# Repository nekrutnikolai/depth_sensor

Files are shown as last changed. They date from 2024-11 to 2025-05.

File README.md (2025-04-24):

## Low-Cost Depth Sensing Module For Deep-Water Instruments

<p align="center">
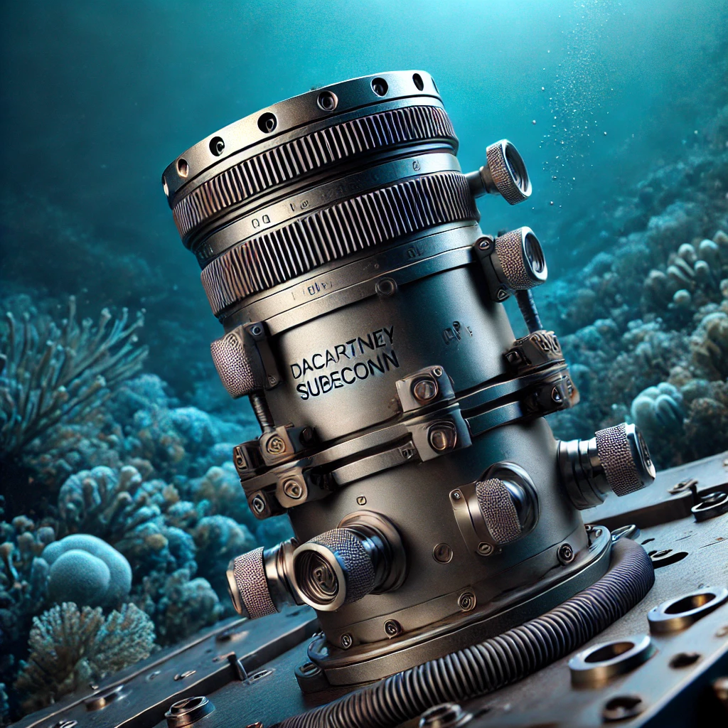
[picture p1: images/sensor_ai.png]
  
</p>

<p align="center">
  AI-generated image of a depth sensor
</p>

<p align="center">
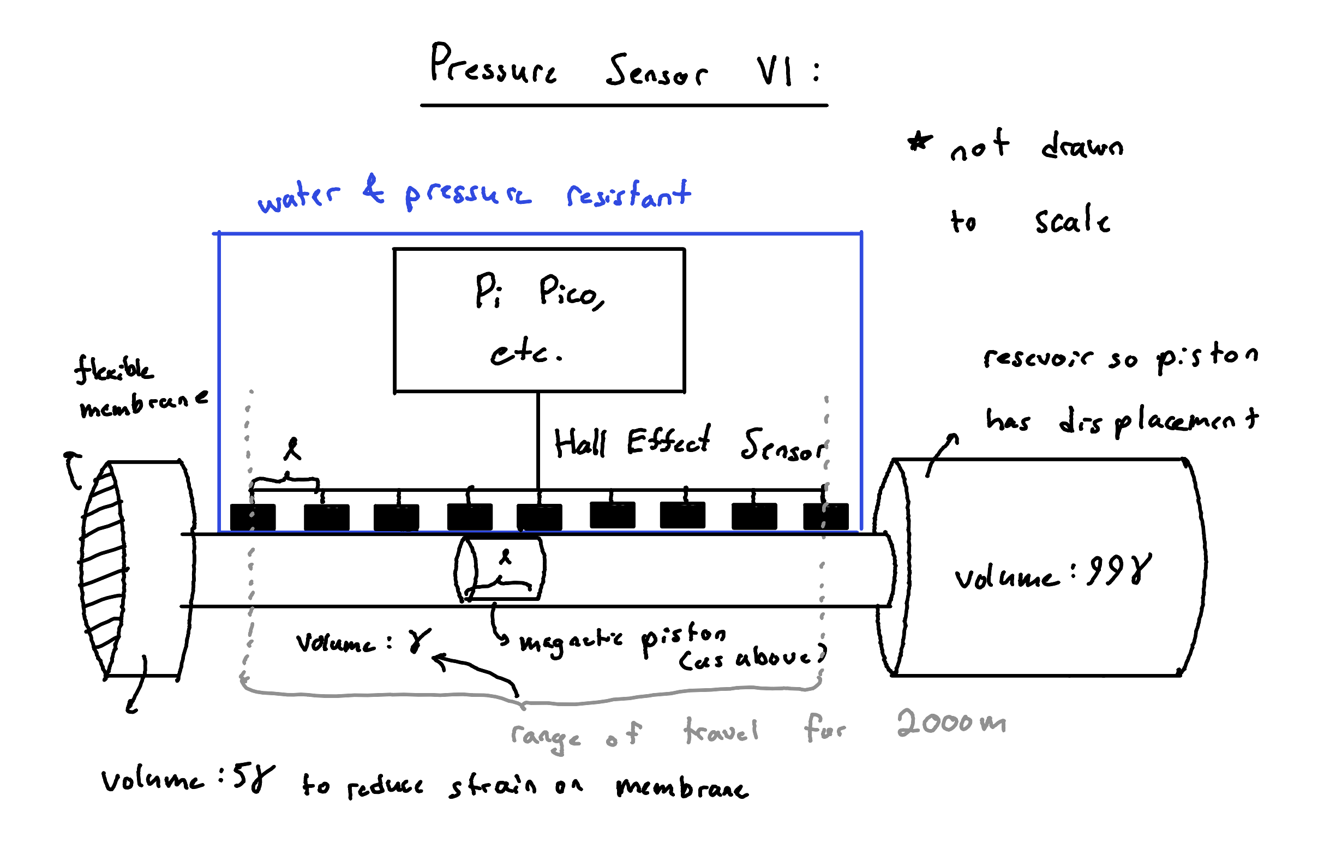
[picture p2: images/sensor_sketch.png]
  
</p>

<p align="center">
  Or here's what the current prototype will look like
</p>

A low-cost, durable depth-sensing module capable of providing approximate depth readings for underwater instruments submerged up to 2000 meters. Deliverables will include a fully functional prototype, field-tested for real-world integration.

> in Partial Fulfillment of the Requirements for the Degree of Master of Engineering, Electrical and Computer Engineering at Cornell University

### Introduction

This project addresses the challenge of developing a cost-effective depth sensor for intermediate to deep depths (up to 2000 meters). Existing solutions are either prohibitively expensive or unsuitable for these depths. In collaboration with Dr. V. Hunter Adams (Cornell ECE) and Jonathan Pfeifer (WHOI), this effort focuses on creating a robust, affordable sensor module designed for integration with underwater exploration vessels. The sensor balances practical accuracy with resilience to high-pressure underwater environments, supporting WHOI’s marine research with an innovative and accessible solution.

### Updates

> Recent on top and older on bottom

#### Potential epoxy options

> Mar 2025

We need ~ 100ml of epoxy to encapsulate electronics and custom break out Pi Pico.

#### Calculating number of hall effect sensors

> Feb 2025

The specification is to be able to work across the 2000m range with a resolution of +/- 10m. 

Thus, the minimum resultion we need to have is 2000m / 10m = 200 points.

From [this article](https://pico-adc.markomo.me/ENOB/), the effective bits of the Pi Pico ADC is approximatle **8.8 bits**.

With a conservative estimate, this is around 2 ^ 8.8 ~ 400 discrete values not affected by noise internal to the ADC

As we can see, even having one hall effect sensor would be enough and would get us to within 5m resolution. 

Since there are three ADCs available on the Pi Pico and the Hall Effect sensors are quite inexpensive, why not utilize three three hall effect sensors for approximately a 3 * 400 ~ 1200 point resolution. For the range of 2000m, this leads to a precision of about 1.67m.

Going beyond that has little benefit

#### Acquiring and plotting live ADC data

> Jan 2025

Wrote program to output ADC data over serial and to a real-time plotter program on my computer where I was measuring the voltage from a potentiometer. This program will serve as a good way to characterize the future hall-effect sensors.

<p align="center">
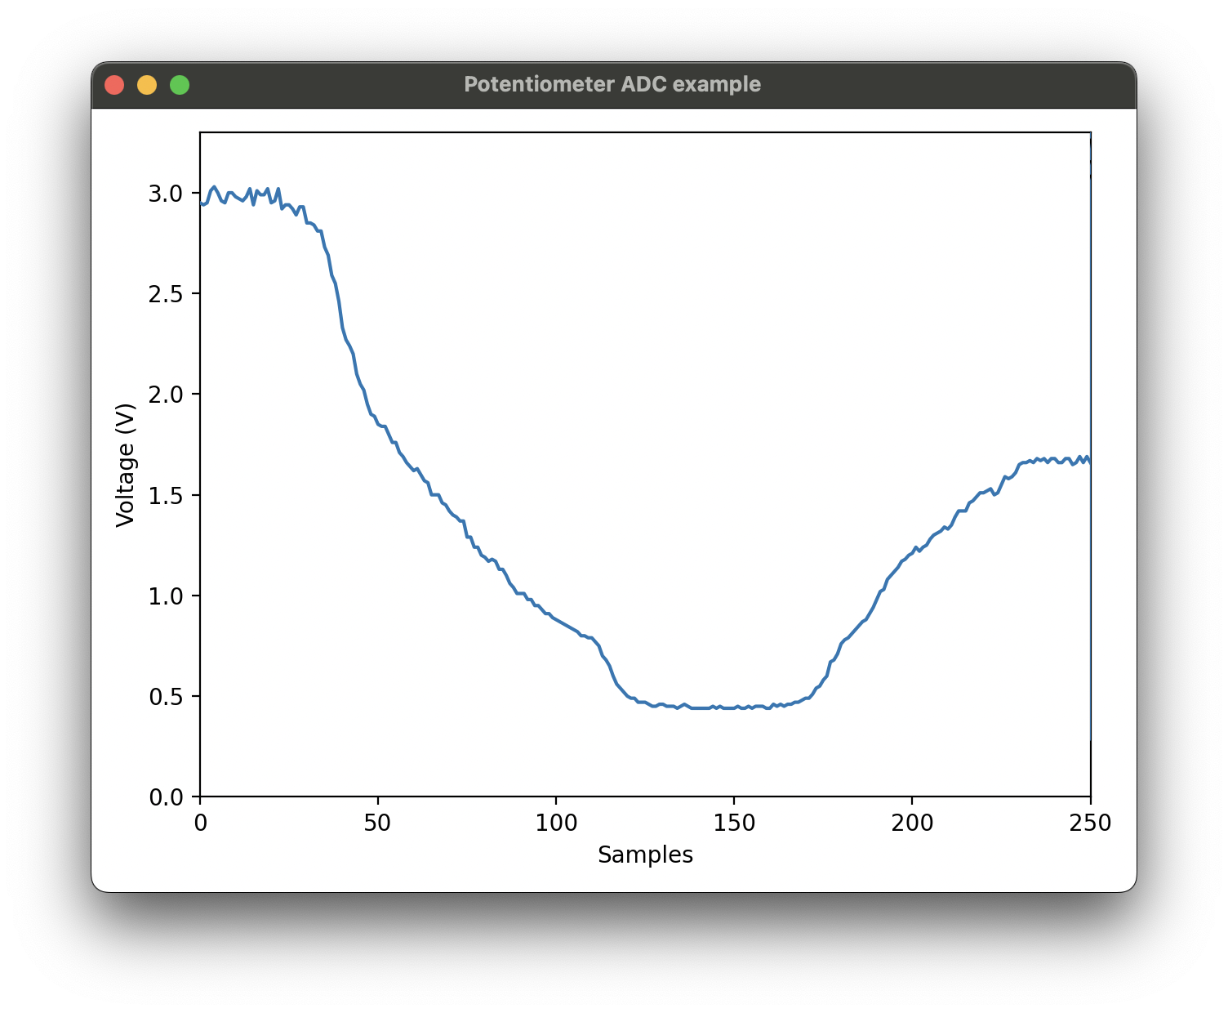
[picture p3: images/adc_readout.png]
  
</p>

<p align="center">
  Live plot of ADC plotter
</p>

<p align="center">
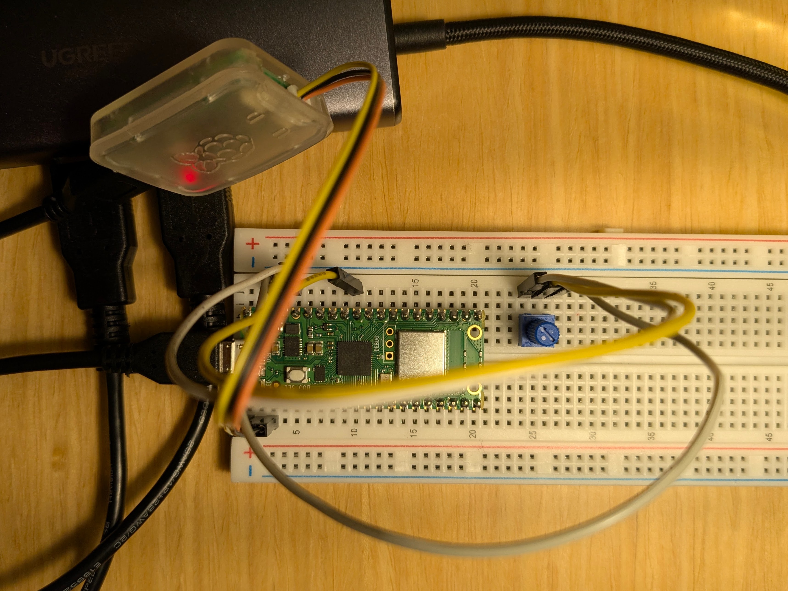
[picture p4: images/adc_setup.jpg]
  
</p>

<p align="center">
  Breadboard setup of potentiometer
</p>

#### Initial PCB design

> Nov 2024

Designed PCB schematic found in /depth_sensor_KiCad as per image below:

<p align="center">
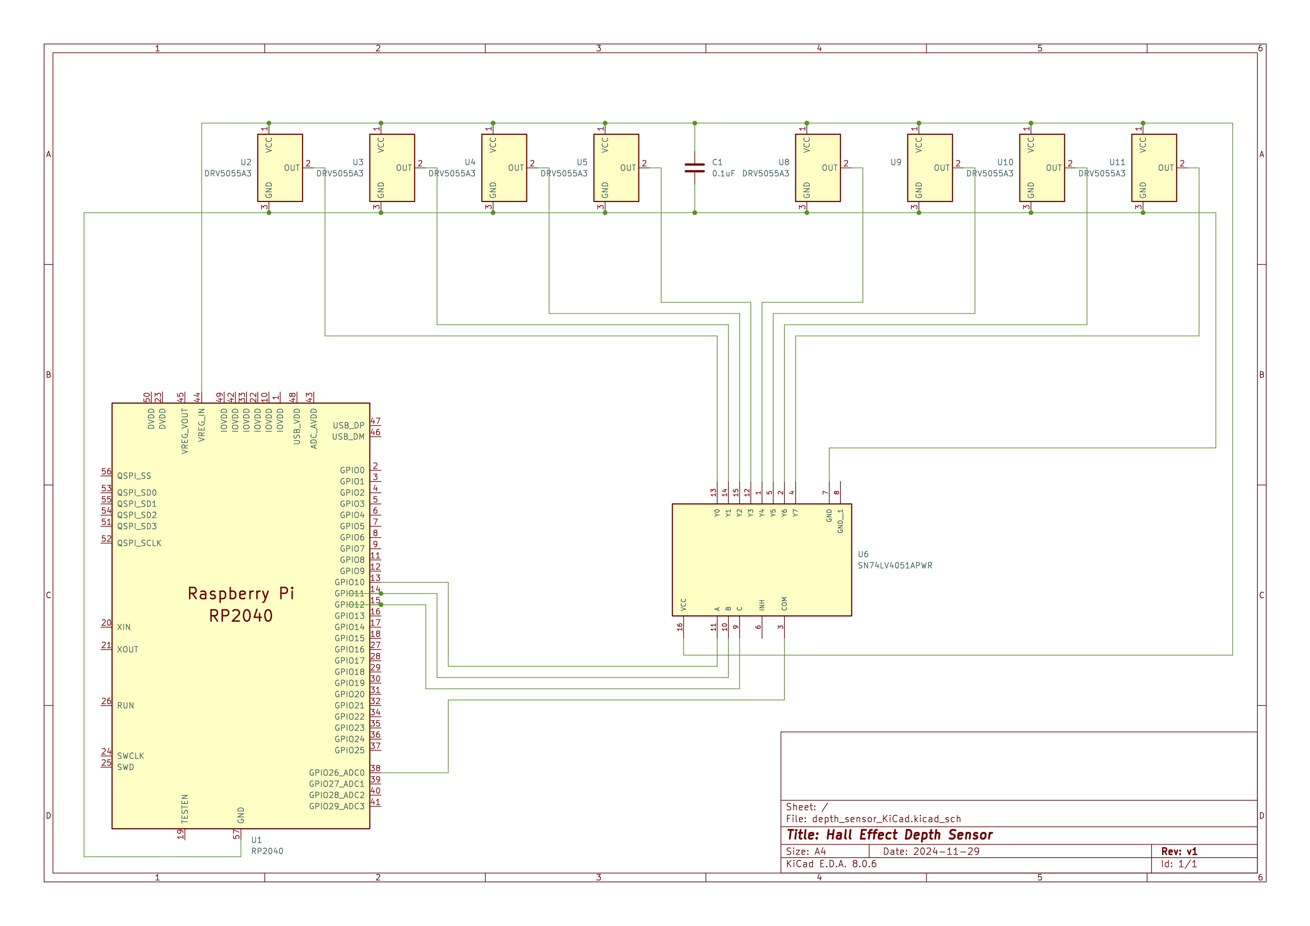
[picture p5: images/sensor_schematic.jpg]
  
</p>

<p align="center">
  Image of schematic
</p>

#### Exploring physical mechanisms with which to measure pressure

> Oct 2024

Compressible fluids research: https://hackmd.io/@nekrutnikolai/rJiTfUMA0

We decided to initially move forward with an approach that utilizes the linear compressibility of liquids, such as sea water, under high pressure. These linearly compressible liquids, such as water or ethanol exhibit an interesting property where their change in volume is linear with respect to pressure rather than a 1/x relationship. The change in volume at a depth of 2000m, which is a pressure of 200 atm is approximately 1% less than atmospheric volume. The prototype will work by having a piston composed of a magnet that moves as the fluid is compressed more and more at greater depths. The position of the magnet is to be determined precisely by using a linear array of hall effect sensors as this is a non-invaise way to measure the position of the magnet.

<!-- Components have arrived but turns out that I received the wrong ones: -->

### Specifications to Meet

| **Parameter** | **Specification** |
|---|---|
| **Depth** | 2,000 m |
| **Pressure** | 200 atm |
| **Power Input** | 5-24V @ ≤ 100mA |
| **Data Protocol**  | RS-232 |
| **Physical Size**  | Soda can - Nalgene bottle sized |
| **Connector Type** | MacArtney SubConn |
| **Accuracy** | ±10 m |
| **Mounting** | Hose clamps, bolts, etc. |

### Timeline  
This project spans two semesters: **FA 2024 - SP 2025** with the following timeline:  

#### Fall 2024 Semester  
- ✅ **Sep-Nov**: Conduct research and finalize physical sensing mechanism  
- ✅ **Nov**: Order components  
- ⬜ **Dec**: Design circuit PCB (in progress)  
- ⬜ **Dec**: Initial testing with ordered components (in progress)  

#### Spring 2025 Semester  
- ⬜ **Jan-Feb**: Design algorithm to translate physical system into depth readings  
- ⬜ **Jan-Feb**: Assemble prototype & test at Helen Newman Pool  
- ⬜ **Feb**: Complete interface design and implement energy-efficient adjustments  
- ⬜ **Feb-Mar**: Integrate final hardware and software, prepare for field testing  
- ⬜ **Mar-Apr**: Perform field testing with WHOI; collect data and refine design  
- ⬜ **May**: Finalize module, complete documentation, and hand over the prototype to WHOI

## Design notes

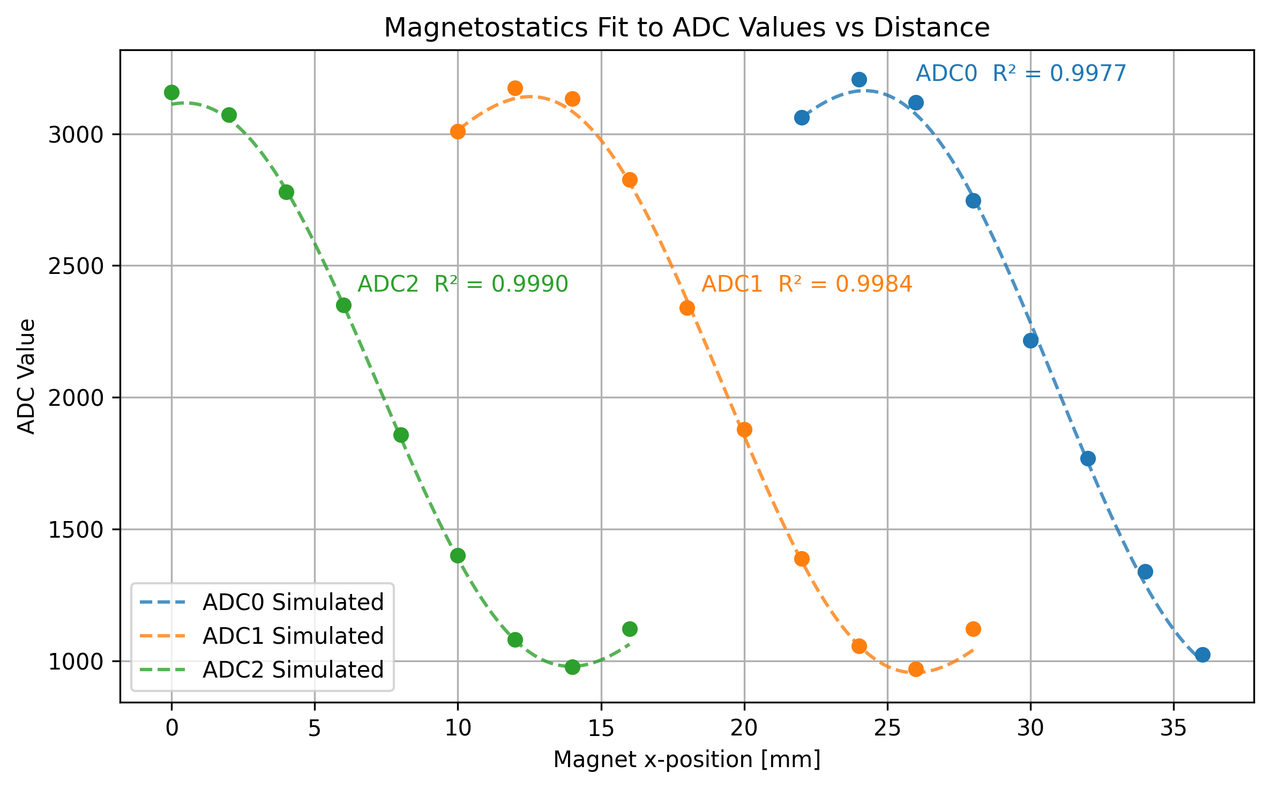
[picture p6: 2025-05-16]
output.png

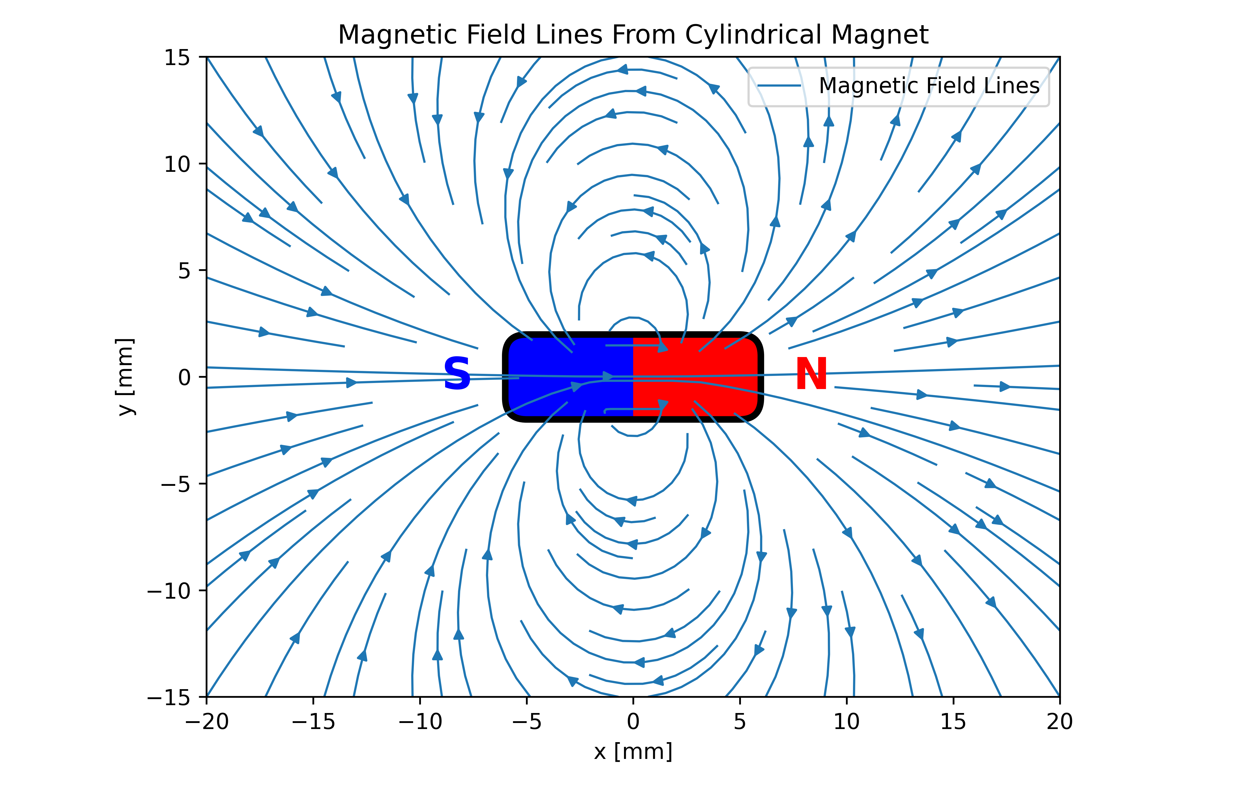
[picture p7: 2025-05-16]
magnetic_field.png

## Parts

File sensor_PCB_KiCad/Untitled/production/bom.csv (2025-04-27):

Designator | Footprint | Quantity | Value | LCSC Part #
C1, C2, C3 | 0603 | 3 | 0.01u
U1, U2, U3 | SOT-23 | 3 | DRV5055A3xDBZxQ1
U4 | PCB_HallEffect | 1 | ~

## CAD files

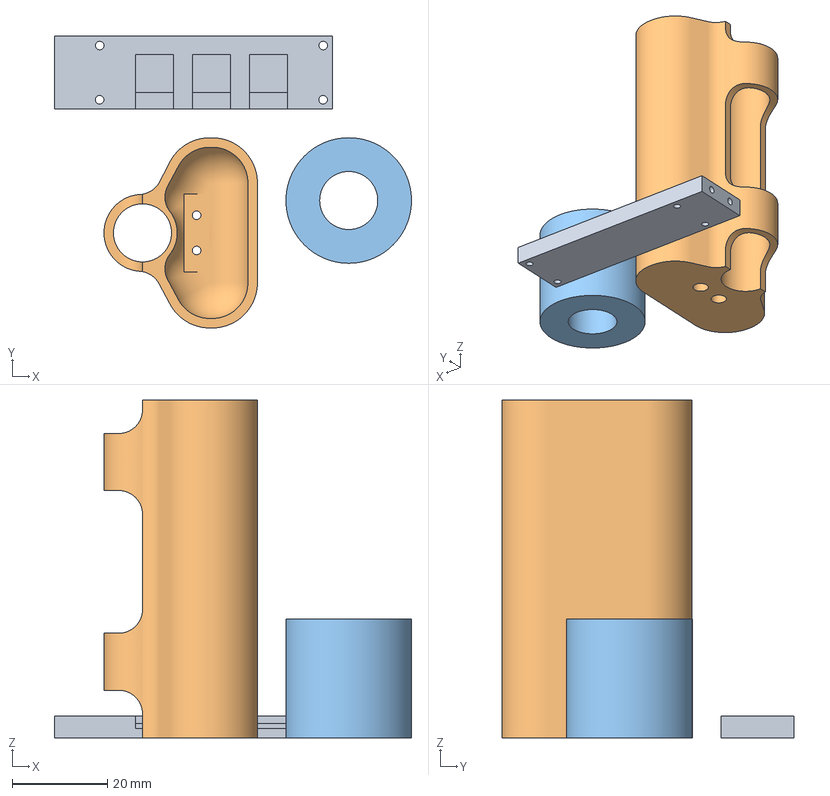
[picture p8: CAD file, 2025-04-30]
Sensor_Test_Jig_PC.3mf
75.1 x 61.4 x 71.0 mm
Sensor Package Mold Part 3.stl
Sensor Package Mold Part 7 (2).stl
Part Studio 1 Part 1.stl

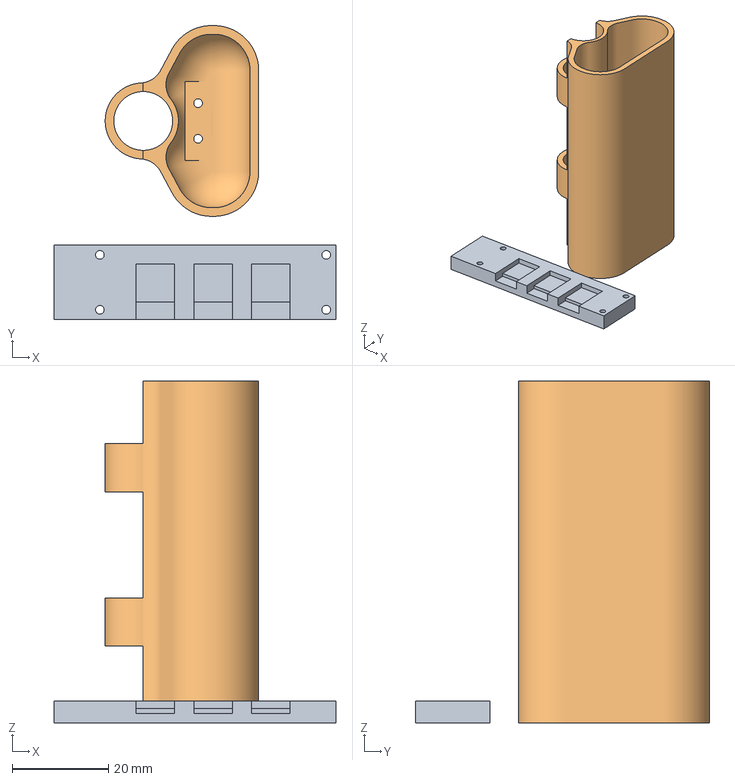
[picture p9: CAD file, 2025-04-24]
Sensor_Test_Jig.3mf
58.5 x 61.0 x 71.0 mm
Sensor Package Mold Part 3.stl
Sensor Package Mold Part 7 (1).stl

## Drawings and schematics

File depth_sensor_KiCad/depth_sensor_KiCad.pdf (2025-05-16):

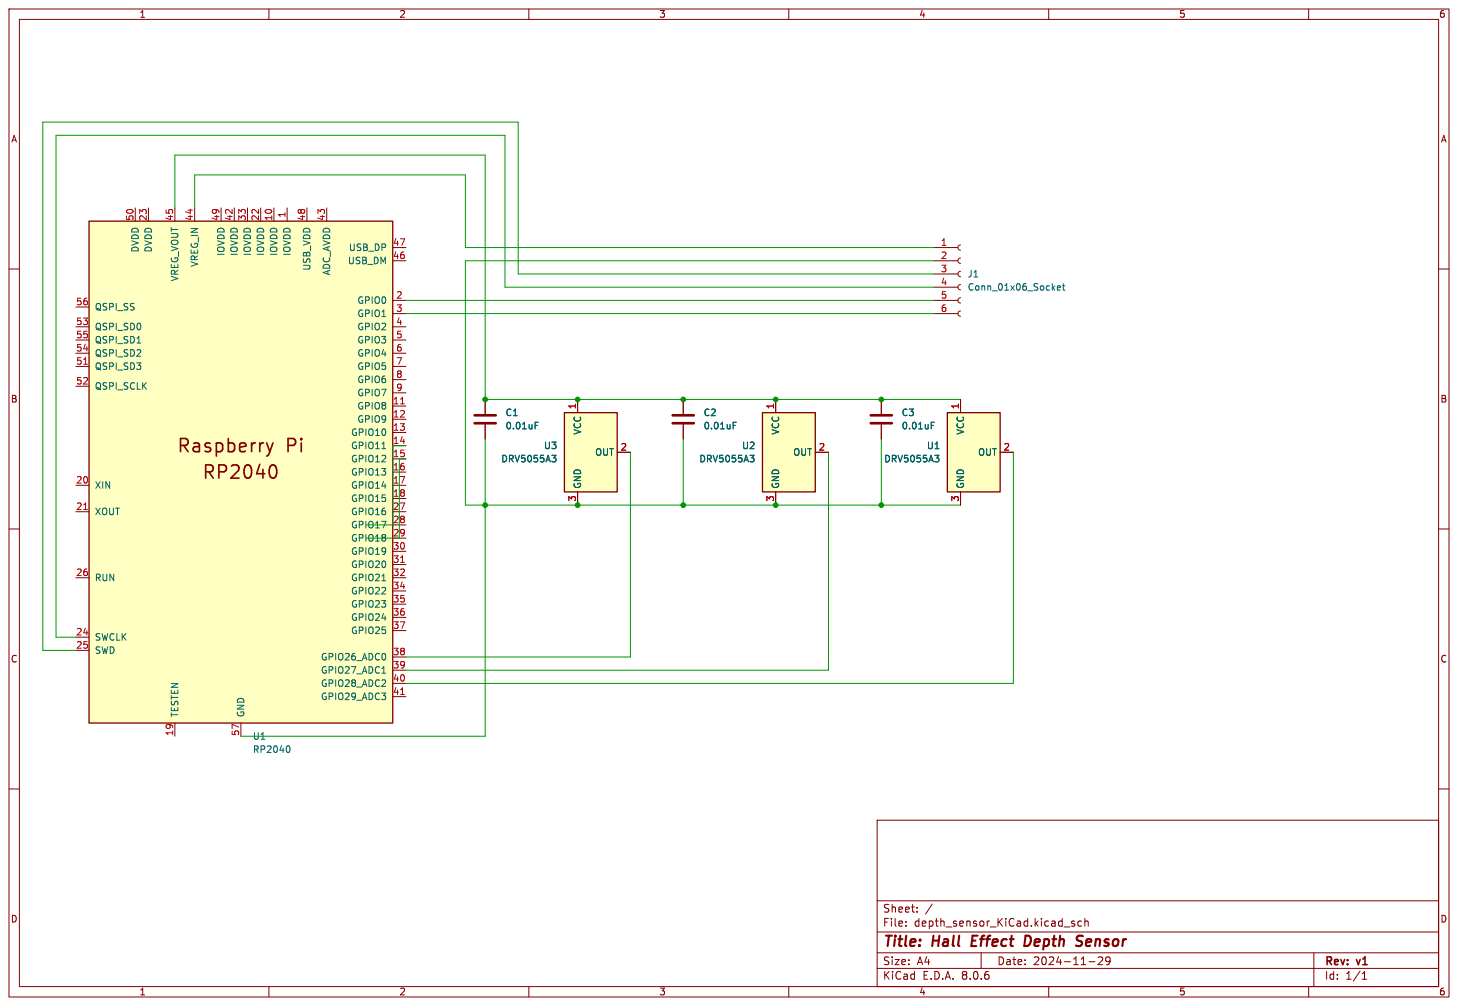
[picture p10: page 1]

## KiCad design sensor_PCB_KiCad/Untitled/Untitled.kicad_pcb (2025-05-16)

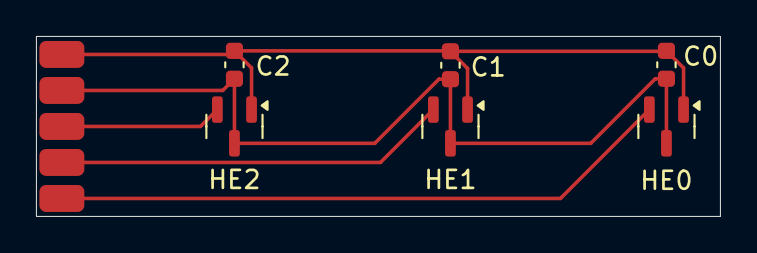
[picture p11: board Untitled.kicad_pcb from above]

Board: 2 copper layers, 38.0 x 10.0 mm, 7 parts (0 on the bottom side), 5 nets.

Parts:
C0, C1, C2: 0.01u; C_0603_1608Metric
HE0: ADC 0; SOT-23
HE1: ADC 1; SOT-23
HE2: ADC 2; SOT-23
U4: PCB_HallEffect

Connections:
+3V3: C0.1, C1.1, C2.1, HE0.1 (VCC), HE1.1 (VCC), HE2.1 (VCC), U4.1 (Vcc)
GND: C0.2, C1.2, C2.2, HE0.3 (GND), HE1.3 (GND), HE2.3 (GND), U4.2 (Gnd)
unnamed: HE0.2 (OUT), U4.5 (ADC_3)
unnamed: HE1.2 (OUT), U4.4 (ADC_2)
unnamed: HE2.2 (OUT), U4.3 (ADC_1)

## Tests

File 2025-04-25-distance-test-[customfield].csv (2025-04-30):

datetime | ms_elapsed | ADC0 | ADC1 | ADC2 | DataType | DataValue
2025-04-25 13:45:26 | 56266 | 2115 | 2247 | 3160 | distance(mm) | 0
2025-04-25 13:45:27 | 57270 | 2115 | 2248 | 3159 | distance(mm) | 0
2025-04-25 13:45:28 | 58275 | 2115 | 2249 | 3159 | distance(mm) | 0
2025-04-25 13:45:29 | 59279 | 2115 | 2248 | 3160 | distance(mm) | 0
2025-04-25 13:45:30 | 60282 | 2115 | 2248 | 3160 | distance(mm) | 0
2025-04-25 13:45:31 | 61286 | 2113 | 2248 | 3158 | distance(mm) | 0
2025-04-25 13:45:32 | 62291 | 2114 | 2248 | 3159 | distance(mm) | 0
2025-04-25 13:45:33 | 63295 | 2114 | 2249 | 3160 | distance(mm) | 0
2025-04-25 13:45:34 | 64300 | 2114 | 2249 | 3159 | distance(mm) | 0
2025-04-25 13:45:35 | 65304 | 2114 | 2249 | 3159 | distance(mm) | 0
2025-04-25 13:45:36 | 66308 | 2114 | 2248 | 3158 | distance(mm) | 0
2025-04-25 13:45:37 | 67312 | 2114 | 2249 | 3158 | distance(mm) | 0
2025-04-25 13:45:38 | 68316 | 2115 | 2248 | 3158 | distance(mm) | 0
2025-04-25 13:46:00 | 90410 | 2124 | 2327 | 3073 | distance(mm) | 2
2025-04-25 13:46:01 | 91415 | 2124 | 2327 | 3073 | distance(mm) | 2
2025-04-25 13:46:02 | 92417 | 2124 | 2328 | 3074 | distance(mm) | 2
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

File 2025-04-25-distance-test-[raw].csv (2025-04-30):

datetime | ms_elapsed | ADC0 | ADC1 | ADC2
2025-04-25 13:44:34 | 4044 | 2847 | 2021 | 1479
2025-04-25 13:44:36 | 6052 | 2290 | 3090 | 1460
2025-04-25 13:44:37 | 7059 | 2145 | 2519 | 2697
2025-04-25 13:44:38 | 8063 | 2116 | 2252 | 3192
2025-04-25 13:44:39 | 9067 | 2104 | 2181 | 2843
2025-04-25 13:44:40 | 10071 | 2100 | 2151 | 2620
2025-04-25 13:44:41 | 11076 | 2094 | 2122 | 2365
2025-04-25 13:44:42 | 12079 | 2098 | 2138 | 2505
2025-04-25 13:44:43 | 13084 | 2100 | 2144 | 2550
2025-04-25 13:44:44 | 14088 | 2103 | 2164 | 2726
2025-04-25 13:44:45 | 15092 | 2101 | 2151 | 2619
2025-04-25 13:44:46 | 16097 | 2099 | 2146 | 2564
2025-04-25 13:44:47 | 17101 | 2096 | 2128 | 2399
2025-04-25 13:44:48 | 18106 | 2095 | 2125 | 2385
2025-04-25 13:44:49 | 19110 | 2098 | 2128 | 2393
2025-04-25 13:44:50 | 20113 | 2096 | 2127 | 2391
2025-04-25 13:44:51 | 21117 | 2097 | 2127 | 2391
2025-04-25 13:44:52 | 22122 | 2097 | 2127 | 2391
2025-04-25 13:44:53 | 23126 | 2098 | 2128 | 2396
2025-04-25 13:44:54 | 24127 | 2099 | 2139 | 2517
2025-04-25 13:44:55 | 25135 | 2102 | 2168 | 2771
2025-04-25 13:44:56 | 26140 | 2108 | 2195 | 2966
2025-04-25 13:44:57 | 27144 | 2110 | 2216 | 3081
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

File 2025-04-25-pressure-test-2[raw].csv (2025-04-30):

datetime | ms_elapsed | ADC0 | ADC1 | ADC2
2025-04-25 14:49:13 | 4072 | 2166 | 2689 | 2020
2025-04-25 14:49:15 | 6094 | 2167 | 2689 | 2020
2025-04-25 14:49:16 | 7099 | 2165 | 2689 | 2019
2025-04-25 14:49:17 | 8103 | 2165 | 2688 | 2020
2025-04-25 14:49:18 | 9107 | 2165 | 2689 | 2021
2025-04-25 14:49:19 | 10110 | 2164 | 2690 | 2020
2025-04-25 14:49:20 | 11114 | 2165 | 2688 | 2020
2025-04-25 14:49:21 | 12120 | 2166 | 2688 | 2019
2025-04-25 14:49:22 | 13123 | 2166 | 2689 | 2020
2025-04-25 14:49:23 | 14128 | 2165 | 2688 | 2019
2025-04-25 14:49:24 | 15132 | 2165 | 2689 | 2020
2025-04-25 14:49:25 | 16136 | 2165 | 2688 | 2020
2025-04-25 14:49:26 | 17141 | 2165 | 2689 | 2019
2025-04-25 14:49:27 | 18145 | 2165 | 2689 | 2020
2025-04-25 14:49:28 | 19148 | 2165 | 2688 | 2019
2025-04-25 14:49:29 | 20153 | 2164 | 2689 | 2019
2025-04-25 14:49:30 | 21155 | 2165 | 2688 | 2020
2025-04-25 14:49:31 | 22162 | 2165 | 2688 | 2020
2025-04-25 14:49:32 | 23166 | 2165 | 2688 | 2018
2025-04-25 14:49:33 | 24170 | 2164 | 2688 | 2021
2025-04-25 14:49:34 | 25174 | 2165 | 2688 | 2020
2025-04-25 14:49:35 | 26178 | 2166 | 2690 | 2020
2025-04-25 14:49:36 | 27182 | 2165 | 2689 | 2019
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

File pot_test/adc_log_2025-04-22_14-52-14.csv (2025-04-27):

timestamp_ms | ADC0 | ADC1 | ADC2
88 | 1.67 | 1.65 | 1.64
179 | 1.69 | 1.66 | 1.66
200 | 1.68 | 1.68 | 1.65
204 | 1.69 | 1.66 | 1.66
205 | 1.69 | 1.67 | 1.67
206 | 1.68 | 1.66 | 1.66
207 | 1.68 | 1.67 | 1.65
208 | 1.68 | 1.68 | 1.67
209 | 1.68 | 1.67 | 1.65
210 | 1.69 | 1.66 | 1.67
211 | 1.69 | 1.67 | 1.64
212 | 1.67 | 1.66 | 1.66
213 | 1.68 | 1.67 | 1.67
214 | 1.68 | 1.67 | 1.67
219 | 1.68 | 1.66 | 1.66
220 | 1.69 | 1.67 | 1.66
229 | 1.68 | 1.67 | 1.67
243 | 1.68 | 1.66 | 1.65
258 | 1.69 | 1.67 | 1.67
271 | 1.69 | 1.66 | 1.67
285 | 1.68 | 1.67 | 1.66
298 | 1.66 | 1.68 | 1.66
312 | 1.68 | 1.67 | 1.66
326 | 1.68 | 1.67 | 1.67
340 | 1.67 | 1.67 | 1.65
354 | 1.67 | 1.67 | 1.65
367 | 1.68 | 1.66 | 1.66
382 | 1.69 | 1.66 | 1.66
396 | 1.67 | 1.67 | 1.66
409 | 1.67 | 1.67 | 1.66
422 | 1.68 | 1.67 | 1.66
436 | 1.68 | 1.66 | 1.66
451 | 1.67 | 1.67 | 1.65
464 | 1.67 | 1.66 | 1.66
478 | 1.68 | 1.67 | 1.65
491 | 1.67 | 1.65 | 1.65
505 | 1.68 | 1.67 | 1.67
520 | 1.67 | 1.66 | 1.67
533 | 1.67 | 1.67 | 1.66
547 | 1.68 | 1.67 | 1.66
560 | 1.68 | 1.65 | 1.65
574 | 1.68 | 1.66 | 1.66
588 | 1.68 | 1.67 | 1.66
602 | 1.67 | 1.67 | 1.66
615 | 1.68 | 1.68 | 1.67
629 | 1.67 | 1.67 | 1.66
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

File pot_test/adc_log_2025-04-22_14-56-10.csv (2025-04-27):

timestamp_ms | ADC0 | ADC1 | ADC2
87 | 1.69 | 1.68 | 1.66
183 | 1.69 | 1.67 | 1.67
205 | 1.69 | 1.66 | 1.66
210 | 1.68 | 1.67 | 1.67
211 | 1.68 | 1.67 | 1.66
212 | 1.68 | 1.67 | 1.66
213 | 1.67 | 1.66 | 1.67
214 | 1.68 | 1.67 | 1.66
215 | 1.68 | 1.67 | 1.66
216 | 1.68 | 1.66 | 1.67
217 | 1.68 | 1.67 | 1.66
218 | 1.68 | 1.66 | 1.66
219 | 1.68 | 1.67 | 1.66
220 | 1.69 | 1.67 | 1.67
221 | 1.68 | 1.67 | 1.65
222 | 1.66 | 1.66 | 1.66
232 | 1.67 | 1.67 | 1.66
247 | 1.68 | 1.65 | 1.67
260 | 1.68 | 1.67 | 1.67
274 | 1.68 | 1.66 | 1.67
288 | 1.67 | 1.68 | 1.65
301 | 1.68 | 1.67 | 1.67
316 | 1.67 | 1.67 | 1.66
329 | 1.68 | 1.68 | 1.67
343 | 1.68 | 1.66 | 1.66
356 | 1.68 | 1.66 | 1.66
371 | 1.68 | 1.66 | 1.66
385 | 1.67 | 1.68 | 1.65
398 | 1.68 | 1.67 | 1.66
412 | 1.69 | 1.67 | 1.65
425 | 1.68 | 1.66 | 1.67
440 | 1.68 | 1.67 | 1.66
454 | 1.68 | 1.67 | 1.67
467 | 1.69 | 1.67 | 1.66
481 | 1.67 | 1.67 | 1.65
494 | 1.68 | 1.67 | 1.66
509 | 1.67 | 1.65 | 1.66
522 | 1.69 | 1.67 | 1.65
536 | 1.68 | 1.66 | 1.67
549 | 1.68 | 1.66 | 1.67
563 | 1.67 | 1.66 | 1.67
578 | 1.67 | 1.65 | 1.67
591 | 1.69 | 1.67 | 1.68
605 | 1.67 | 1.67 | 1.67
618 | 1.69 | 1.67 | 1.67
632 | 1.67 | 1.66 | 1.66
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

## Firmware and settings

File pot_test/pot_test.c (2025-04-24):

/**
 * Copyright (c) 2021 Raspberry Pi (Trading) Ltd.
 *
 * SPDX-License-Identifier: BSD-3-Clause
 */

#include <stdio.h>
#include "pico/stdlib.h"
#include "hardware/gpio.h"
#include "hardware/adc.h"
#include "hardware/uart.h"

/* Example code to extract analog values from a microphone using the ADC
   with accompanying Python file to plot these values

   Connections on Raspberry Pi Pico board, other boards may vary.

   GPIO 26/ADC0 (pin 31)-> AOUT or AUD on microphone board
   3.3v (pin 36) -> VCC on microphone board
   GND (pin 38)  -> GND on microphone board
*/

#define ADC_NUM 0
#define ADC_PIN (26 + ADC_NUM)
#define ADC_VREF 3.3
#define ADC_RANGE (1 << 12)
#define ADC_CONVERT (ADC_VREF / (ADC_RANGE - 1))

int main() {
    stdio_init_all();
    sleep_ms(1000);
    printf("Beep boop, listening...\n");

    adc_init();

    // Initialize GPIO pins for ADC0, ADC1, and ADC2
    for (int adc_num = 0; adc_num < 3; adc_num++) {
        adc_gpio_init(26 + adc_num);
    }

    uint adc_raw;
    while (1) {
        for (int adc_num = 0; adc_num < 3; adc_num++) {
            adc_select_input(adc_num); // Select the ADC input
            adc_raw = adc_read();     // Read raw voltage from ADC
            // printf("ADC%d: %.2f V\n", adc_num, adc_raw * ADC_CONVERT);
            printf("ADC%d: %d\n", adc_num, adc_raw);
            // printf("Serial test OK\n");
        }
        sleep_ms(10);
    }
}

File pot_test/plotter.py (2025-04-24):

#!/usr/bin/env python3

import serial
import sys
import csv
import datetime
import matplotlib.pyplot as plt
import matplotlib.animation as animation
from matplotlib.lines import Line2D
from time import time

plt.rcParams['toolbar'] = 'None'

class Plotter:
    def __init__(self, ax):
        self.ax = ax
        self.maxt = 10000
        self.tdata = [0]
        self.ydata = {
            0: [4096 / 2],
            1: [4096 / 2],
            2: [4096 / 2]
            # 0: [3.3 / 2],
            # 1: [3.3 / 2],
            # 2: [3.3 / 2],
        }
        self.lines = {
            0: Line2D(self.tdata, self.ydata[0], color='C0', label='ADC0'),
            1: Line2D(self.tdata, self.ydata[1], color='C1', label='ADC1'),
            2: Line2D(self.tdata, self.ydata[2], color='C2', label='ADC2'),
        }

        for line in self.lines.values():
            self.ax.add_line(line)

        self.ax.set_ylim(0, 4096)
        # self.ax.set_ylim(0, 3.3)
        self.ax.set_xlim(0, self.maxt)
        self.ax.legend(loc='upper right')

    def update(self, adc_vals):
        timestamp = int((time() - start_time) * 1000)  # ms since start
        csv_writer.writerow([
            timestamp, adc_vals[0], adc_vals[1], adc_vals[2]
        ])

        lastt = self.tdata[-1]
        if lastt - self.tdata[0] >= self.maxt:
            self.tdata = self.tdata[1:]
            for ch in self.ydata:
                self.ydata[ch] = self.ydata[ch][1:]
            self.ax.set_xlim(self.tdata[0], self.tdata[0] + self.maxt)

        t = lastt + 1
        self.tdata.append(t)
        for ch in adc_vals:
            self.ydata[ch].append(adc_vals[ch])
            self.lines[ch].set_data(self.tdata, self.ydata[ch])

        return tuple(self.lines.values())

def serial_getter():
    buffer = {}
    while True:
        line = ser.readline().decode(errors='ignore').strip()
        if line.startswith("ADC"):
            try:
                parts = line.split(":")
                chan = int(parts[0][3])
                val = int(parts[1].strip())
                buffer[chan] = val
            except Exception:
                continue

            if all(k in buffer for k in [0, 1, 2]):
                yield {0: buffer[0], 1: buffer[1], 2: buffer[2]}
                buffer.clear()

# --- Setup ---
if len(sys.argv) < 2:
    raise Exception("Usage: python3 plotter.py <serial_port>")

ser = serial.Serial(sys.argv[1], 115200, timeout=1)

# Create CSV file with timestamped filename
now = datetime.datetime.now().strftime("%Y-%m-%d_%H-%M-%S")
csv_filename = f"adc_log_{now}.csv"
csv_file = open(csv_filename, "w", newline='')
csv_writer = csv.writer(csv_file)
csv_writer.writerow(["timestamp_ms", "ADC0", "ADC1", "ADC2"])

start_time = time()

fig, ax = plt.subplots()
plotter = Plotter(ax)

ani = animation.FuncAnimation(
    fig, plotter.update, serial_getter, interval=1,
    blit=True, cache_frame_data=False
)

ax.set_xlabel("Samples")
ax.set_ylabel("ADC Value")
fig.canvas.manager.set_window_title('3-Channel ADC Plotter')
fig.tight_layout()

try:
    plt.show()
finally:
    csv_file.close()
    print(f"Saved data to {csv_filename}")

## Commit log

2024-11-29 plotted PCB v1
    [depth_sensor_KiCad.kicad_pcb, depth_sensor_KiCad.kicad_sch]
2025-02-09 worked on sensor code
2025-04-24 added code
    [Sensor_Test_Jig.3mf, Sensor_Test_Jig_PC.3mf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]
2025-04-27 added .csv files
    [adc_log_2025-04-22_14-52-14.csv, adc_log_2025-04-22_14-56-10.csv, adc_log_2025-04-23_12-01-02.csv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]
2025-04-30 added more data
    [2025-04-25-distance-test-[customfield].csv, 2025-04-25-distance-test-[raw].csv, 2025-04-25-pressure-test-2[raw].csv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]
2025-05-16 added latest changes
    [Untitled.kicad_pcb, depth_sensor_KiCad.kicad_sch]
